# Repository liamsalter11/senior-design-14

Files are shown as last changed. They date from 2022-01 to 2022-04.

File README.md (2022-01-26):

# senior-design-14
Visible Light Communication

Project Description: 

Students  will design  a digital communication system that represents data by flashing a 
light source, and which can operate in an environment that includes ambient lighting. 

Project Specifications: 

The system will include a transmitter that represents binary or multi-level data symbols 
by varying the amplitude, phase, or frequency of the flashing light, and a receiver that 
can decode the transmitted data by sensing the variations in light intensity. 

The system must be able to operate in a room that includes ambient lighting. 

The  receiver  must  optimal,  in  the  sense  that  the  received  signal  is  processed 
according to an algorithm that minimizes the bit error rate when the received signal is 
observed in additive white Gaussian noise. 

There will be an option in the transmitter to include a simple error-correction coding 
scheme, and in the receiver to decode the bits and correct some errors, so that the bit 
error rare is reduced. 

The  system  must  be  able  to  achieve  a  bit  error  rate  of  less  than  0.01  over  short 
distances without error-correction coding. 

The  team  must  test  the  system  over  a  range  of  distances  between  transmitter  and 
receiver. Statistical measures must be calculated that quantify the bit error rate as a 
function of distance. 

The team must test the system with and without error-correction coding, and quantify 
the improvement in bit error rate that results from the coding scheme.

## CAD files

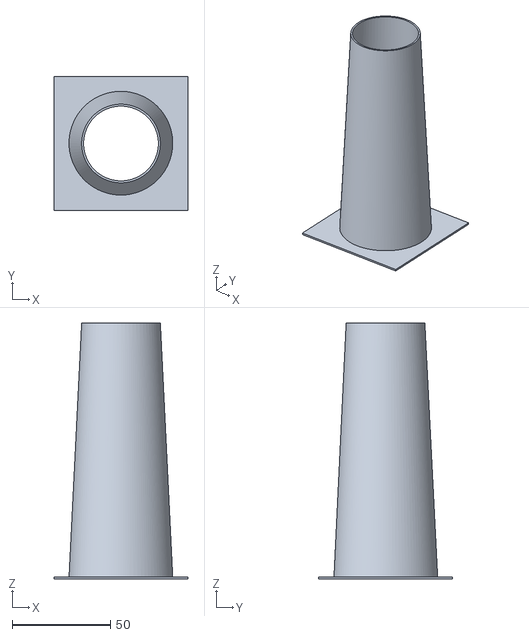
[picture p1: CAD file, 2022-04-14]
TX_enclosure/Lenses.stl
68.0 x 68.0 x 130.1

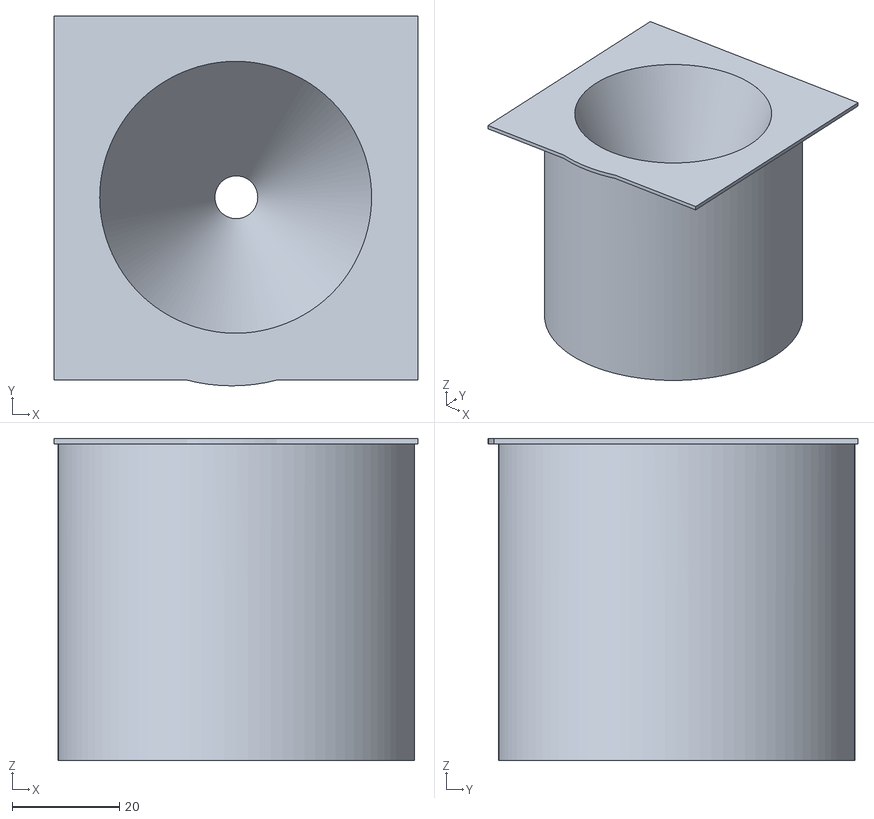
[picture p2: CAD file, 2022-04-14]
TX_enclosure/LEDtoFresnel.stl
68.0 x 69.1 x 60.2

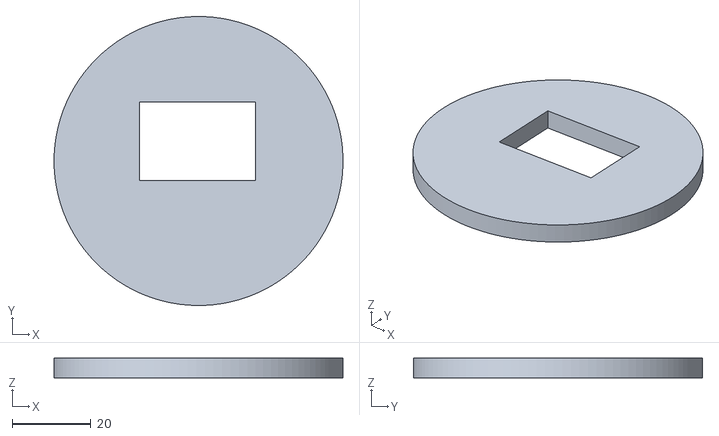
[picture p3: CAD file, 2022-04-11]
TX_enclosure/Cap.stl
73.4 x 73.4 x 5.00

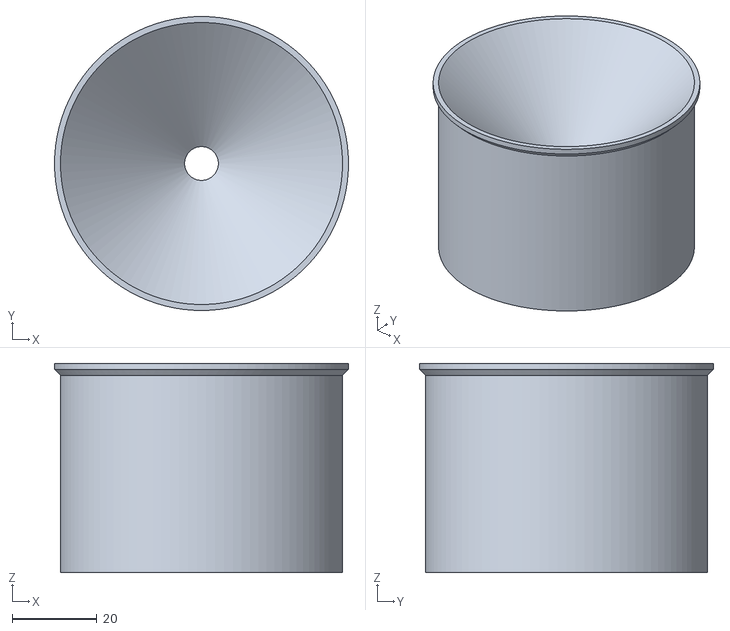
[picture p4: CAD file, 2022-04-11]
TX_enclosure/Lens.stl
69.4 x 69.4 x 49.4

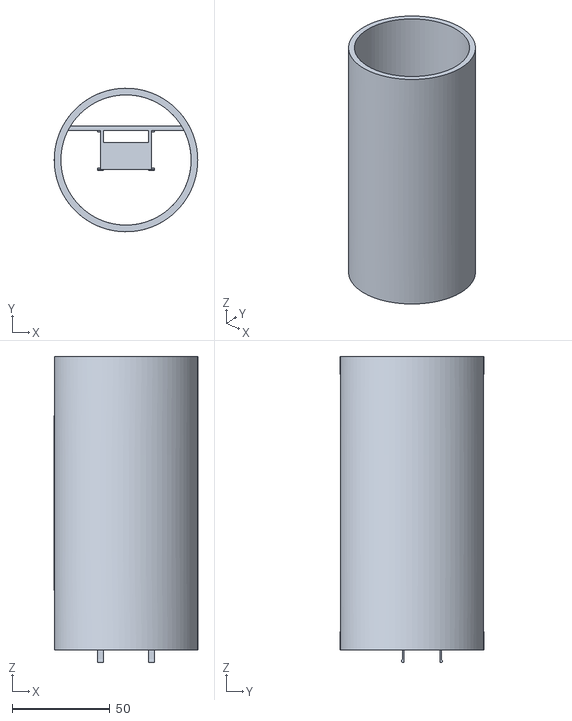
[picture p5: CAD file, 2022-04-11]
TX_enclosure/Tube.stl
73.4 x 73.4 x 156.5

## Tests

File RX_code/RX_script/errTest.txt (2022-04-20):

hey there king
here's an error aaaak test

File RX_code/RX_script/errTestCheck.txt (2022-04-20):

hey there king
here's an error chehk test

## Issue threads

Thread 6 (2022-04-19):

Error checking appears to count symbol errors

pbrazzle, 2022-04-19:
Character differences must be compared bit by bit to get an accurate bit error rate. The current script seems to count a single error if the characters are different

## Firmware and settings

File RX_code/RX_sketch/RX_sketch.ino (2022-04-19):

// a 11111111 indicates the start and end of transmission
#include <Vector.h>

#include "LiFiCorrection.hpp"

using namespace LiFiData;

# define BLUE 7
# define GREEN 9
# define RED 10
# define CLK 9
//# define BLUE 7
# define interruptPin 13
# define interruptControllerPin 12

# define maxSize 200
# define maxFrames 100

const int transRate = 1000; //us
//const int frameDelay = 300; //ms
//10 bits in a frame, 0-9
const int frameSize = 10;

//variables and objects for interrupt handling
int edge = 0;
volatile bool frameDone = false;
volatile bool sampleDone = false;
volatile bool interrupting = false;
volatile int bitsReceived = 0;


volatile int state = 0;
int frameStartTime = 0;
bool frameStartLock = false;
bool gotNumFrames = false;

//byte array to store message

unsigned int storageArray[maxFrames*2];
Vector<unsigned int> dataVector(storageArray);

LiFiData::Bitset receivedBits(MAX_BITSET_LENGTH);

unsigned int numFrames = 0;
unsigned int numFramesReceived = 0;

unsigned int receivedFrame=0;

/***Serial Print Functions***/

void printStartUpMessage(void)
{
  //Serial.print("Welcome! We are waiting for the message to be transmitted to us.\n");
}


void printDataVector()
{
  Serial.println("");
  for(int i =0; i<dataVector.size()-1;i++)
  {
    Serial.print((char)dataVector.at(i));
  //  Serial.print(" ");
  //  Serial.print(dataVector.at(i));
  //Serial.println();
  }
}

void printBitSet()
{
  //get rid of header and footer
  dataVector.remove(0);
  dataVector.pop_back();

  receivedBits.setLength(dataVector.size()*8);
  
  for(int i=0; i<dataVector.at(i);i++)
  {
    for(int j=0; j<8;j++)
    {
      if(bitRead(dataVector.at(i), 7-j)==1)
      {
        receivedBits.set((i*8)+j);
      }
    }
  }
  //Serial.println("\nReceived Bits:");
  //Serial.println(receivedBits.asString());
  //Serial.println(receivedBits[5]);
  //Serial.println("\nDeocoded:");
  receivedBits = LiFiCorrection::decodeErrors(receivedBits);
  Serial.println(receivedBits.asASCIIString());
  //Serial.println(receivedBits.asString());


  
}

/***Do Stuff Functions***/

void setup() 
{
  //pinMode(binaryInput, INPUT);
  
  Serial.begin(19200);
  
  pinMode(interruptControllerPin, OUTPUT);
  pinMode(BLUE, INPUT);
  pinMode(GREEN, INPUT);
  pinMode(RED,INPUT);
  pinMode(interruptPin, INPUT);

  digitalWrite(interruptControllerPin,HIGH);
  
  attachInterrupt(digitalPinToInterrupt(interruptPin), edgeInterrupt, RISING);

  //setup onshot timer that counts between each sample taken during a frame
  //sampleTimer.setDurationMsec((double)(transRate));
}

//interrupt handler

void edgeInterrupt(void)
{
  interrupting = true;
  state = 5;
  //Serial.println("trigger");
}

void getFrame(void)
{
  //detach the interrupt so that it doesnt trigger inside of a frame
  detachInterrupt(digitalPinToInterrupt(interruptPin));
  //noInterrupts();
  //Serial.println("edge interrupt");
  //Serial.println(micros());
  
  receivedFrame = 0;
  frameDone = false;
  sampleDone = false; 
  volatile int sample = 0;
  int startTime = 0;
  while(!frameDone)
  { 
    
    //Serial.println(frameDone);
    
    //trigger the sampling timer, if the timer is over then restart the timer, restart the timer for the next frame
    /*if(sampleTimer.isRunning() == 0)
    {
      sampleTimer.restart();
    }
    sampleTimer.pause();
    sampleTimer.start();*/
    //Serial.print(sampleDone);
    //Serial.print(frameDone);
    startTime = micros();
    while(!sampleDone && !frameDone) 
    {
      
      //Serial.print(" ");
      //Serial.print(sample);
      digitalRead(BLUE) ? sample++ : sample--;
      //sampleTimer.update();

      int t = transRate + startTime;
      if(micros() >= t)
      {
        sampleDone = true;
        bitsReceived++;
        if(bitsReceived == frameSize)
        {
          frameDone = true;
          //Serial.println("frameDone");
          bitsReceived = 0;
        }
      }

    }    
    //reset the conditional
    sampleDone = false;
    //Serial.println(sample);
    receivedFrame = receivedFrame<<1;
    if(sample > 0)
      receivedFrame++;
  
    //reset the sample counter
    sample = 0;       
  }
  
  //Serial.println(receivedFrame, BIN);
  frameHandler(receivedFrame);
  //Serial.println("end of interrupt ");
  //digitalWrite(interruptControllerPin, HIGH);
  //Serial.println(micros());
  //reset the conditional
  //frameDone = false;
  interrupting = false;
  attachInterrupt(digitalPinToInterrupt(interruptPin), edgeInterrupt, RISING);
  //interrupts();  
}

void getFrameRB(void)
{
  //detach the interrupt so that it doesnt trigger inside of a frame
  detachInterrupt(digitalPinToInterrupt(interruptPin));
  //noInterrupts();
  //Serial.println("edge interrupt");
  //Serial.println(micros());
  
  unsigned int receivedFrameR = 0;
  unsigned int receivedFrameB = 0;
  frameDone = false;
  sampleDone = false; 
  volatile int sampleB = 0;
  volatile int sampleR = 0;
  int startTime = 0;
  while(!frameDone)
  { 
    
    //Serial.println(frameDone);
    
    //trigger the sampling timer, if the timer is over then restart the timer, restart the timer for the next frame
    /*if(sampleTimer.isRunning() == 0)
    {
      sampleTimer.restart();
    }
    sampleTimer.pause();
    sampleTimer.start();*/
    //Serial.print(sampleDone);
    //Serial.print(frameDone);
    startTime = micros();
    while(!sampleDone && !frameDone) 
    {
      
      //Serial.print(" ");
      //Serial.print(sample);
      digitalRead(BLUE) ? sampleB++ : sampleB--;
      digitalRead(RED) ? sampleR++ : sampleR--;

      //sampleTimer.update();

      int t = transRate + startTime;
      if(micros() >= t)
      {
        sampleDone = true;
        bitsReceived++;
        if(bitsReceived == frameSize)
        {
          frameDone = true;
          //Serial.println("frameDone");
          bitsReceived = 0;
        }
      }

    }    
    //reset the conditional
    sampleDone = false;
    //Serial.println(sample);
    receivedFrameB = receivedFrameB<<1;
    if(sampleB > 0)
      receivedFrameB++;

    receivedFrameR = receivedFrameR<<1;
    if(sampleR > 0)
      receivedFrameR++;
  
    //reset the sample counter
    sampleR = 0;
    sampleB = 0; 

    
  }
  //Serial.print("blu");
  frameHandler(receivedFrameB);
  //Serial.print("red");
  frameHandler(receivedFrameR);

  interrupting = false;
  attachInterrupt(digitalPinToInterrupt(interruptPin), edgeInterrupt, RISING);
}

void getFrameRGB(void)
{
  //detach the interrupt so that it doesnt trigger inside of a frame
  detachInterrupt(digitalPinToInterrupt(interruptPin));
  
  receivedFrame = 0;
  frameDone = false;
  sampleDone = false; 
  volatile int sampleR = 0, sampleG = 0, sampleB = 0;
  int startTime = 0;
  while(!frameDone)
  {
    //trigger the sampling timer, if the timer is over then restart the timer, restart the timer for the next frame
    startTime = micros();
    while(!sampleDone && !frameDone) 
    {
      digitalRead(GREEN) ? sampleG++ : sampleG--;
      digitalRead(BLUE) ? sampleB++ : sampleB--;
      digitalRead(RED) ? sampleR++ : sampleR--;

      int t = transRate * 1000 + startTime;
      if(micros() >= t)
      {
        sampleDone = true;
        bitsReceived++;
        if(bitsReceived == frameSize)
        {
          frameDone = true;
          bitsReceived = 0;
        }
      }

    }
      
    //reset the conditional
    sampleDone = false;

    receivedFrame = receivedFrame << 3;
    receivedFrame |= ((sampleB > 0) << 2) | ((sampleG > 0) << 1) | (sampleR > 0);
  
    //reset the sample counter
    sampleR = 0;
    sampleG = 0;
    sampleB = 0; 
  }
  
  frameHandler(receivedFrame);

  interrupting = false;
  attachInterrupt(digitalPinToInterrupt(interruptPin), edgeInterrupt, RISING); 
}

void frameHandler(unsigned int inputFrame)
{
  //Serial.println(inputFrame, BIN);
 
    //get rid of frame footer 
    //0111111110 is the mask, gets rid of all start/stop bits
    inputFrame = inputFrame>>1;
    uint8_t bitMask = 255;
    
    inputFrame = inputFrame & bitMask;
    dataVector.push_back(inputFrame);

}


void resetSystem(void)
{
 
  Serial.flush();
  frameStartLock = false;
  gotNumFrames = false;
  dataVector.clear();
  
  for(int i =0;i<MAX_BITSET_LENGTH;i++)
    receivedBits.clear(i);
    
  //Serial.println("resettging daatat");
  //printDataVector();
  
  //Serial.print("\nRestarting..... \n \n");
}

void loop() 
{
  
  //Serial.print("State \n");
  switch(state)
  {
    case 0:
      printStartUpMessage();
      if(!interrupting)
        state=6;
      break;

    case 1:
      
      //the header of the transmission was received  
      //Serial.print("header State"); 
      if(dataVector.front()==255)
      {
        //Serial.println("header received");
        frameStartLock = true;
        if(!interrupting)  
          state=7;
      }
      else
      {
       if(!interrupting)   
          state=1;
      }
      
      break;
      
    case 2:
      //the number of frames was received
      if(numFramesReceived >= numFrames)
      {  
        //Serial.println(interrupting);
        //if(!interrupting)
        //{
          //Serial.println("fuck");
          state = 3;
        //}
      }
      else 
      {
        if(!interrupting)
          state = 2;
      }
      break;
    
    case 3:
      //Serial.print("staet 3");
      //printMessageToSerial(convertToString(wholeBIN));
      printDataVector();
      //printBitSet();
      
      if(!interrupting)
        state = 4;
        
    case 4:
      resetSystem();
      //delay(2000);
      state=1;
      break;
    case 5:
      //state in which the entire frame is sampled
      getFrame();
      
      if(gotNumFrames == true)
      {
        numFramesReceived++;
        //Serial.println(numFramesReceived);
      }
       
      if(!frameStartLock)
      {
        //Serial.println("locking");
        frameStartLock = true;
        state = 1;
      }
      else if(!gotNumFrames)
        state = 7;
      else
        state = 2;
      
      break; 
      
    case 6:
      state=6;
      break;

    case 7:
      //case to get the number of frames received
      //wait until the number of frames being transmitted is received
      if(dataVector.size()==2 && !gotNumFrames)
      {
        numFrames = dataVector.at(1);
        gotNumFrames = true;
        /*
        Serial.print("# frames: ");
        Serial.print(numFrames);
        Serial.println();*/
        if(!interrupting)
          state = 2;
      }
      else
      { 
        if(!interrupting)
          state = 7;
      }
      break;
      
  }
  /*if(frameDone == true)
    attachInterrupt(digitalPinToInterrupt(interruptPin), edgeInterrupt, RISING);*/


}

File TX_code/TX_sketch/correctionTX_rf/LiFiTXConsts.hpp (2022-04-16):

#ifndef LIFITXCONSTS
#define LIFITXCONSTS

//LED GPIO pins
const int LED_PIN_B = 11;
const int LED_PIN_G = 12;
const int LED_PIN_R = 13;
const int LED_PIN_CLOCK = 4;

//LiFi System Parameters
const int TRANSMISSION_RATE = 1; //Bit time in milliseconds
const int FRAME_DELAY = 5;		 //Frame delay time in milliseconds
const int FRAME_SIZE = 10;	
const bool USE_CORRECTION = true;	

#endif

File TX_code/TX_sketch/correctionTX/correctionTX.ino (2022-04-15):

#include <Vector.h>
#include "LiFiCorrection.hpp"
//#include "Bitset.hpp"

using namespace LiFiData;

//constant for defining the max size
#define maxSize 200
#define baud 1200
#define maxFrames 100

//vars for getting string
String userString;
byte charByte[7]; //array for converting char into bin
byte charByteSum=0; //array for store the final value of a char's bin
byte wholeBIN[maxSize]; //replace the number with the max number of characters

unsigned int storageArray[maxFrames];
Vector<unsigned int> frames(storageArray);

//Bitset for correction
LiFiData::Bitset convolBits(LiFiData::MAX_BITSET_LENGTH);

//loop vars 
int state;

char line[100];
int count = 0;

//blinking variables
//green =12
//blue = 11
//red = 13
char ledMessage[7];
const int binaryLED = 11; //blue
const int binaryLEDg = 12;
const int binaryLEDr = 13;
const int clockLED = 4;

const int transRate = 1;  //100ms
const int frameDelay = 5; //300ms
//10 bits in a frame, 0-9
const int frameSize = 9;

/***Serial Print Functions***/

void startUpPrompt(void)
{
  //delay(3000);
  Serial.println("Hello! You can input a message below and have it turned into binary!");
  //double hertz = 1/(transRate);
  //Serial.print(hertz);
 // Serial.print(" khz");
  Serial.println("Enter Message: "); 
}

void printAllBinary(void)
{ 
  Serial.println("----------");
  Serial.print("Whole message is:\n");
  for(unsigned int i = 0; i < frames.size(); i++)
  {
    //Serial.print("print loop");
    /*if(wholeBIN[i] == 0)
      continue;*/
    Serial.print(frames.at(i),BIN);
    
    Serial.print(" ");
  }
  Serial.println("\n----------");
}

void printAllConvolBits(void)
{
  Serial.println("----------");
  Serial.print("Convoled message is:\n");
  Serial.print(convolBits.getLength());
  for(int i = 0; i<convolBits.getLength();i++)
  {
    //Serial.print("asdas");
    Serial.print(convolBits[i], BIN);
    Serial.print(" ");
  }
}

/***Doing Stuff Functions***/

void setup() {
  // put your setup code here, to run once:
  Serial.begin(19200);
  Serial.print("Starting\n");

  pinMode(binaryLED, OUTPUT);
  pinMode(binaryLEDg, OUTPUT);
  pinMode(binaryLEDr, OUTPUT);
  
  pinMode(clockLED, OUTPUT);

  digitalWrite(clockLED, LOW);
  digitalWrite(binaryLED, LOW);
  digitalWrite(binaryLEDg, LOW);
  digitalWrite(binaryLEDr, LOW);

  state = 1;
}

void convertString2Binary(String inputMessage)
{
  //add header
  addTransmissionStartEnd();
  int messageLength = inputMessage.length();
  char inputChars[messageLength]; 
  char inByte;
  int inputPosition=0;
  
  char letter;
  int bytes[messageLength];
    
  for(int i=0; i<messageLength-1; i++)
  {
    letter = inputMessage.charAt(i);
    wholeBIN[i] = inputMessage.charAt(i);
    frames.push_back(generateFrame(letter));  
  }
 
  //error correction
  //Make Bitset from data (10 bits per frame?)
  LiFiData::Bitset rawData(frames.size()*10);
  for(int i =0; i<frames.size();i++)
  {
    for(int j =0; j<9; j++)
     {
        if(bitRead(frames.at(i),j) == 1)
        {
          rawData.set((10*i)+j);
        }
     }
  }
  convolBits = LiFiCorrection::convolve(rawData);  
  
  //add footer
  addTransmissionStartEnd();
}

bool getInputMessage(void)
{
  if (Serial.available() > 0) 
  {
  
    line[count] = (char)Serial.read(); // store the char
    if (line[count++] == '\n'){        // if its a CR,
       line[count] = '\0';             //  zero-terminate it
       Serial.println("----------\nYour message is: ");
       Serial.println(line);           //  and print it.
       userString = line;
       if(userString.length()>1)  
         return(true);
         
       Serial.println("loop");         // re-prompt
       count = 0;                      //  and reset the index.
    }
  }

  return(false);
}

void resetSystem(void)
{
  userString="";
  line[0]='\0';
  count=0;
  for(unsigned int i = 0; i < maxSize; i++)
  {
    wholeBIN[i] = 0;
  }

  frames.clear();
  digitalWrite(clockLED, LOW);
  digitalWrite(binaryLED, LOW);
  digitalWrite(binaryLEDg, LOW);
  digitalWrite(binaryLEDr, LOW);
  Serial.flush();
  Serial.print("\nRestarting..... \n \n");
}


void addTransmissionStartEnd(void)
{
    frames.push_back(generateFrame(255));
    Serial.println("adding header/footer");
}

unsigned int generateFrame(byte charByte)
{
  //frame is: [header][zero pad][data][footer]

  //header is binary 1
  unsigned int frame = 1;

  //shift in and add byte
  frame = frame << 8;
  frame |= charByte;

  //add footer which is zero
  frame = frame << 1;
  //frame = frame | 1;
  
 /* Serial.print("\n------ frame:");
  Serial.print(frame); 
  Serial.print("  ");
  Serial.print(frame,BIN); 
  Serial.print("-----\n");*/

  return frame;
}


void printFrames(void)
{
  
  for(unsigned int i =0; i<frames.size();i++)
  {
    for(unsigned int j = 0; j<frameSize; j++)
    {
      //Serial.print("frameSize");
      uint8_t singleBit = bitRead(frames.at(i),frameSize-j);
      digitalWrite(binaryLED, singleBit);

      //wait a clock period before sending another bit
      unsigned int waitTime = transRate * 1000 + micros();
      while(micros() <= waitTime);
    }
    
    digitalWrite(binaryLED, LOW);
    
    //delay between frames
    unsigned int frameWaitTime = frameDelay * 1000 + micros();
    while(micros() <= frameWaitTime);
  }
}

void sendConvolBits(void)
{
  
  for(int i =0; i<frames.size();i++)
  {
    for(unsigned int j = 0; j<frameSize; j++)
    {
      //Serial.print("frameSize");
      uint8_t singleBit = convolBits[(10*i)+j];
      digitalWrite(binaryLED, singleBit);

      //wait a clock period before sending another bit
      unsigned int waitTime = transRate * 1000 + micros();
      while(micros() <= waitTime);
    }
    
    digitalWrite(binaryLED, LOW);
    
    //delay between frames
    unsigned int frameWaitTime = frameDelay * 1000 + micros();
    while(micros() <= frameWaitTime);
  }
}

void printFramesRGB(void)
{
  // PortA 16, 19, 17
  // Pins  11, 12, 13
  for(unsigned int i = 0; i < frames.size(); i++)
  {
    for(unsigned int j = 0; j < frameSize; j += 3)
    {
      //Serial.print("frameSize");
      uint8_t bitR = bitRead(frames.at(i), frameSize - j + 2);
      uint8_t bitG = bitRead(frames.at(i), frameSize - j + 1);
      uint8_t bitB = bitRead(frames.at(i), frameSize - j);
      digitalWrite(binaryLED, bitB);
      digitalWrite(binaryLEDg, bitG);
      digitalWrite(binaryLEDr, bitR);

      //wait a clock period before sending another bit
      unsigned int waitTime = transRate * 1000 + micros();
      while(micros() <= waitTime);
       
    }
    digitalWrite(binaryLED, LOW);
    digitalWrite(binaryLEDg, LOW);
    digitalWrite(binaryLEDr, LOW);
    //delay between frames
    unsigned int frameWaitTime = frameDelay * 1000 + micros();
    while(micros() <= frameWaitTime); 
  }
}
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

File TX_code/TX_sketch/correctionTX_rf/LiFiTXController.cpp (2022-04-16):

#include "LiFiTXController.hpp"

#include "LiFiTXConsts.hpp"

using LiFiData::Bitset;

//Used to group multiple GPIO pins at once
struct Pinset
{
	int length;
	int pins[3];
};

//Writes to all pins in a pinset
void writeToPinset(const Pinset& pins, bool val)
{
	for (int i = 0; i < pins.length; i++) digitalWrite(pins.pins[i], val);
}

//Delays for 1 bit time
void waitBitTime()
{
	int waitTime = 1000*TRANSMISSION_RATE + micros();
	while(micros() <= waitTime);
}

//Delays for 1 frame delay time
void waitFrameTime()
{
	int waitTime = 1000*FRAME_DELAY + micros();
	while(micros() <= waitTime);
}

//Sends a 10-bit frame starting from index
void sendFrame(const Bitset& bits, const Pinset& pins, int index)
{
	for (int i = 0; i < FRAME_SIZE; i++)
	{
		for (int j = 0; j < pins.length; j++) digitalWrite(pins.pins[j], bits[i+index+j]);
		waitBitTime();
	}
}
	
//Sends a full Bitset 
void sendBitset(const Bitset& bits, const Pinset& pins)
{	
	for (int i = 0; i < bits.getLength(); i += FRAME_SIZE)
	{
		sendFrame(bits, pins, i);
		writeToPinset(pins, LOW);
		waitFrameTime();
	}
}

//Sends a Bitset over a single LED
void LiFiTXController::TXOneChannel(const LiFiData::Bitset& data)
{
	Serial.println("\nNow sending message");
	Pinset pins = {1, {LED_PIN_B, 0, 0}};
	sendBitset(data, pins);
	Serial.println("Bitset sent");
}

//Sends a Bitset over all 3 LEDs
void LiFiTXController::TXThreeChannel(const LiFiData::Bitset& data)
{
	Pinset pins = {3, {LED_PIN_B, LED_PIN_R, LED_PIN_G}};
	sendBitset(data, pins);
}

//Sets all LED pins to given val
void LiFiTXController::setAllLEDs(bool val)
{
	digitalWrite(LED_PIN_R, val);
	digitalWrite(LED_PIN_G, val);
	digitalWrite(LED_PIN_B, val);
	digitalWrite(LED_PIN_CLOCK, val);
}

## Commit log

2022-01-23 Hello World!
    First work with a prototype that can send and receive with a clock signal
2022-02-09 Add files via upload
    updated to print the whole bin number. still need to add the cut
2022-02-14 Add files via upload
    added led to show binary off of pin7
2022-02-20 updated version of the transmitter code
    replaces firstCheckOff.ino
    [tansmissonEnter.ino]
2022-02-22 added liam's receiver class
    should work similarly to liams code but it will print messages and convert the message to string
2022-02-24 works when wired
2022-03-16 Transmitter PCB
    [PCB1.PcbDoc, Sheet1.SchDoc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]
2022-03-23 Add files via upload
    not working receiver. gets 1 frame successfully and then stalls
2022-03-25 3 frame
2022-03-29 cleaned up some prints but it still worksssss
2022-03-30 3/30 it works. trust me, it's the wires
2022-04-08 Making Arduino compatible versions of correction code
2022-04-09 Transmitter Files
    [Cap.stl, Lens.stl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]
2022-04-11 Correction code is Arduino ready
2022-04-14 New enclosure files
    [LEDtoFresnel.stl, Lenses.stl]
2022-04-14 split by frame instead of by bit
2022-04-15 Spring cleaning. Also changed folder name for easier verification
2022-04-15 Preliminary Spring cleaning
2022-04-15 The great clean
    [Cap.stl, LEDtoFresnel.stl, Lens.stl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]
2022-04-15 Fixed some issues in error reporting
    [ErrorCheck.py]
2022-04-15 Added secret shortcut to transmit script
    [TransmitInterface.py]
2022-04-16 No more over 100% error rate
    [ErrorCheck.py]
2022-04-16 added error correction i think supposedly
    [LiFiTXConsts.hpp, correctionTX_rf.ino]
2022-04-16 TX works with error correction!
    [LiFiTXConsts.hpp, correctionTX_rf.ino]
2022-04-16 Comments & fixed sendBitset
    [LiFiTXController.cpp, LiFiTXSerial.cpp]
2022-04-19 Sends header and number of frames instead of footer
2022-04-19 receives number of frames but gets stuk
2022-04-19 gets number of frames but gets stuk
2022-04-19 mostly counts frames
2022-04-19 TX main refactor
    the transmitter wasn't really a state machine so that was removed
    broke the main loop into decoupled functions
    [correctionTX_rf.ino]
2022-04-19 frameHandler simplification
2022-04-19 FRAME_SIZE used in linker
2022-04-19 Took Interrupts out of main script
2022-04-19 Removed usued Interrupt functions
2022-04-20 Edited error rate script
    [ErrorCheck.py]
